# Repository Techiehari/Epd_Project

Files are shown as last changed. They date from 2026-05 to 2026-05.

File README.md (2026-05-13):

# Epd_Project: 3.3V to 15V Boost Converter

## Overview
This repository contains the KiCad design files for a custom DC-to-DC power converter. The circuit is designed to take a 3.3V input and provide a regulated 15V output at 1A, using the MP3429 IC.

## Key Specifications
* **Input Voltage:** 3.3V
* **Output Voltage:** 15V
* **Output Current:** 1A
* **Core IC:** MPS MP3429

## Tools Used
* **EDA Software:** KiCad
* **Custom Footprints/Symbols:** Designed specifically for the MP3429 and associated components.

## Repository Structure
* `/Custom_libraries` - Contains project-specific library files.
* `/models` - 3D models for PCB visualization.
* `/MP3429_Custom.pretty` - Custom footprint library for the MP3429 IC.
* `/symbols` - Custom schematic symbols.
* `Bom.csv` - Bill of Materials containing component selection and costs.
* `Epd_Project.kicad_sch` - The main KiCad schematic file.
* `Epd_Project.kicad_pcb` - The main KiCad PCB layout file.

## Design Details
Detailed design equations, component selection justifications, and technical specifications derived from the MP3429 datasheet are maintained in the project report documents.

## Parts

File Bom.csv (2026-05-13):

Reference | Value | Datasheet | Footprint | Qty | Mouser Part Number | Price INR | Datasheet links
BT1 | 3.3 | ~ | TerminalBlock_Phoenix:TerminalBlock_Phoenix_PT-1,5-2-5.0-H_1x02_P5.00mm_Horizontal | 1
C9 | 0.1uF |  |  |  | 603-CC805KPX7R9BB104 | 1.12 | https://www.mouser.in/datasheet/3/508/1/UPY_GPHC_X7R_6_3V_TO_250V.pdf
C2 | 0.1uF | ~ | Capacitor_SMD:C_0805_2012Metric | 2 | 603-CC805KPX7R9BB104 | 1.12 | https://www.mouser.in/datasheet/3/508/1/UPY_GPHC_X7R_6_3V_TO_250V.pdf
C3 | 6.8nF | ~ | Capacitor_SMD:C_0805_2012Metric | 1 | 80-C0805C682F5GECLR | 137.91 | https://www.mouser.in/datasheet/3/508/1/KEM_C1091_C0G_ESD.pdf
C4 | 4.7uF | ~ | Capacitor_SMD:C_0805_2012Metric | 1 | 80-C0805X475K3RAUTO | 61.5 | https://www.mouser.in/datasheet/3/72/1/C0805X475K3RACAUTO.pdf
C5 | 22uF |  |  |  | 581-12063D226KAT2A | 106.23 | https://www.mouser.in/datasheet/3/5926/1/cx5r_KGM.pdf
C6 | 22uF | ~ | Capacitor_SMD:C_1206_3216Metric | 6 | 581-12063D226KAT2A | 106.23 | https://www.mouser.in/datasheet/3/5926/1/cx5r_KGM.pdf
C7 | 22uF |  |  |  | 581-12063D226KAT2A | 106.23 | https://www.mouser.in/datasheet/3/5926/1/cx5r_KGM.pdf
C8 | 22uF |  |  |  | 581-12063D226KAT2A | 106.23 | https://www.mouser.in/datasheet/3/5926/1/cx5r_KGM.pdf
C11 | 22uF |  |  |  | 581-12063D226KAT2A | 106.23 | https://www.mouser.in/datasheet/3/5926/1/cx5r_KGM.pdf
C12 | 22uF |  |  |  | 581-12063D226KAT2A | 106.23 | https://www.mouser.in/datasheet/3/5926/1/cx5r_KGM.pdf
C10 | 22nF | ~ | Capacitor_SMD:C_0805_2012Metric | 1 | 80-C0805C223M1RAUTO | 30.75 | https://www.mouser.in/datasheet/3/508/1/KEM_C1023_X7R_AUTO_SMD.pdf
IC1 | MP3429GL-P | https://www.monolithicpower.com/en/documentview/productdocument/index/version/2/document_type/Datasheet/lang/en/sku/MP3429GL-Z/document_id/1189/ | MP3429_Custom:MP3429GLP | 1 | 946-MP3429GL-P | 267.43 | https://www.monolithicpower.com/en/documentview/productdocument/index/version/2/document_type/Datasheet/lang/en/sku/MP3429GL-Z
L1 | 3.3uH |  | Inductor_SMD:L_7.3x7.3_H4.5 | 1 | 704-EXLA1V0605-3R3-R | 86.66 | https://www.eaton.com/content/dam/eaton/products/electronic-components/resources/data-sheet/eaton-exla1v06-automotive-high-current-molded-inductor-data-sheet-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
R1 | 130k | ~ | Resistor_SMD:R_0805_2012Metric | 1 | 71-CRCW0805130KFKEAC | 9.32 | https://www.vishay.com/docs/20035/dcrcwe3.pdf
R2 | 20k | ~ | Resistor_SMD:R_0805_2012Metric | 1 | 71-CRCW080520K0FKEBC | 35.41 | https://www.vishay.com/docs/20035/dcrcwe3.pdf
R3 | 6.8k | ~ | Resistor_SMD:R_0805_2012Metric | 1 | 71-CRCW08056K80FKEAC | 9.32 | https://www.vishay.com/docs/20035/dcrcwe3.pdf
R4 | 30k | ~ | Resistor_SMD:R_0805_2012Metric | 1 | 71-CRCW080530K0FKEAC | 9.32 | https://www.vishay.com/docs/20035/dcrcwe3.pdf
R5 | 750k | ~ | Resistor_SMD:R_0805_2012Metric | 1 | 71-CRCW0805750KFKEAC | 35.41 | https://www.vishay.com/docs/20035/dcrcwe3.pdf
R6 | 53.6k | ~ | Resistor_SMD:R_0805_2012Metric | 1 | 71-CRCW080553K6FKEAC | 9.32 | https://www.vishay.com/docs/20035/dcrcwe3.pdf

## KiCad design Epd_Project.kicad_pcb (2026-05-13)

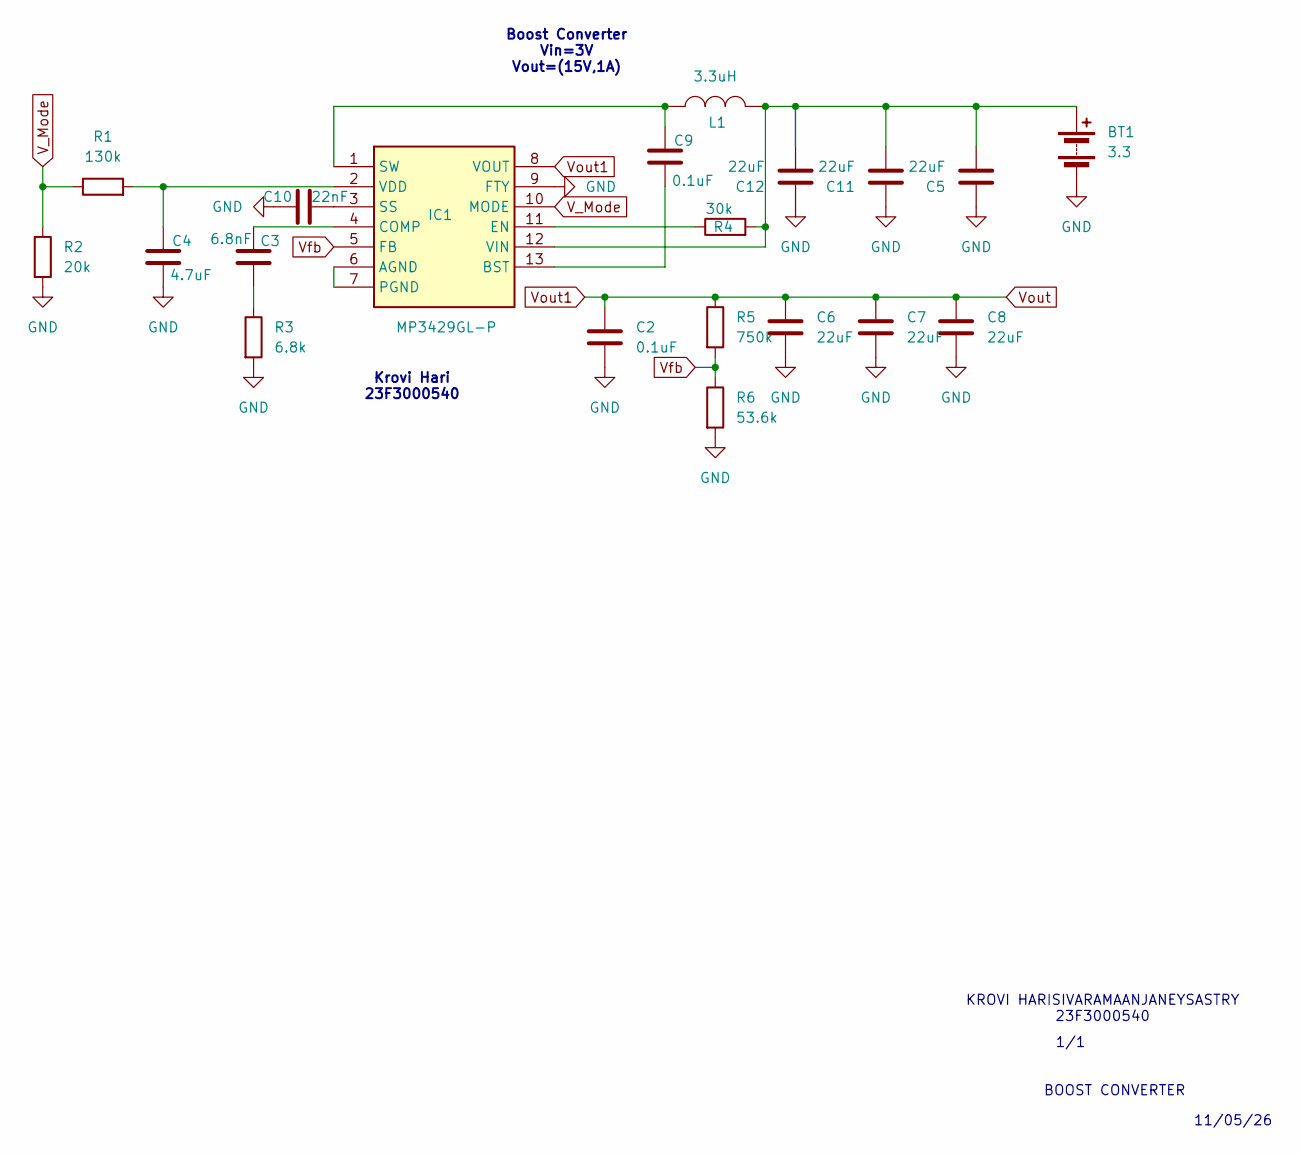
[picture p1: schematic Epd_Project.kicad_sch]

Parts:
BT1: 3.3; TerminalBlock_Phoenix_PT-1,5-2-5.0-H_1x02_P5.00mm_Horizontal
C2, C9: 0.1uF; C_0805_2012Metric
C3: 6.8nF; C_0805_2012Metric
C4: 4.7uF; C_0805_2012Metric
C5, C6, C7, C8, C11, C12: 22uF; C_1206_3216Metric
C10: 22nF; C_0805_2012Metric
IC1: MP3429GL-P; MP3429GLP; Mouser Part Number 946-MP3429GL-P
L1: 3.3uH; L_7.3x7.3_H4.5
R1: 130k; R_0805_2012Metric
R2: 20k; R_0805_2012Metric
R3: 6.8k; R_0805_2012Metric
R4: 30k; R_0805_2012Metric
R5: 750k; R_0805_2012Metric
R6: 53.6k; R_0805_2012Metric

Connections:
GND: BT1.2 (-), C2.2, C4.2, C5.1, C6.2, C7.2, C8.2, C10.1, C11.1, C12.1, IC1.9 (FTY), R2.2, R3.2, R6.2
unnamed: BT1.1 (+), C5.2, C11.2, C12.2, IC1.12 (VIN), L1.2 (T2), R4.2
unnamed: C3.2, R3.1
unnamed: IC1.6 (AGND), IC1.7 (PGND)
unnamed: C9.2, IC1.13 (BST)
unnamed: C3.1, IC1.4 (COMP)
unnamed: IC1.11 (EN), R4.1
unnamed: C10.2, IC1.3 (SS)
unnamed: C9.1, IC1.1 (SW), L1.1 (T1)
unnamed: C4.1, IC1.2 (VDD), R1.2
V_Mode: IC1.10 (MODE), R1.1, R2.1
Vfb: IC1.5 (FB), R5.2, R6.1
Vout: C2.1, C6.1, C7.1, C8.1, IC1.8 (VOUT), R5.1

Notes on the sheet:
Boost Converter Vin=3V Vout=(15V,1A)
KROVI HARISIVARAMAANJANEYSASTRY 23F3000540
11/05/26
BOOST CONVERTER
Krovi Hari 23F3000540
1/1

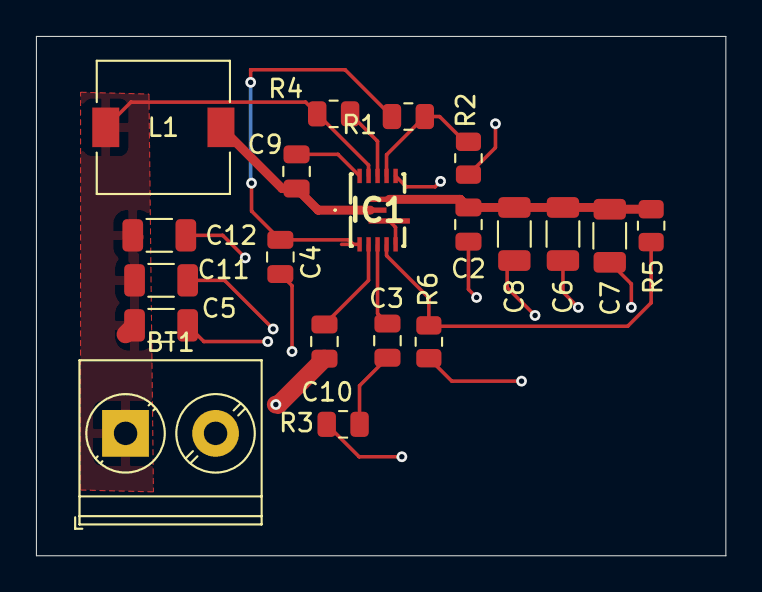
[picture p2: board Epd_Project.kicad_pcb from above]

Board: 2 copper layers, 38.3 x 28.9 mm, 20 parts (0 on the bottom side), 13 nets.
